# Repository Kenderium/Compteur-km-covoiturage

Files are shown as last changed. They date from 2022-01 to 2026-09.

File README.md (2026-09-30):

# The Carpool Project (CarpoX)

Covoiturez-vous souvent ? CarpoX est un boîtier à mettre dans la voiture qui
mesure au GPS les km de chaque trajet et note qui était à bord grâce à des
badges RFID. Une app calcule ensuite qui doit combien à qui, en tenant compte
de qui a payé chaque plein.

## Comment ça marche

```
 Boîtier (Pico W)                     Serveur Linux                App web (téléphone / PC)
 GPS + badges RFID  ── WiFi connu ──▶  API + base SQLite  ◀── HTTPS ──  comptes, pleins, soldes
        ▲                                                                    │
        └──────────────────────── Bluetooth (BLE) ───────────────────────────┘
               synchro via le téléphone, association des badges
```

1. **Dans la voiture** : on badge le conducteur puis les passagers, et le
   boîtier compte les km au GPS jusqu'à l'arrivée.
2. **Synchronisation** : dès que le boîtier voit un WiFi connu (maison, partage
   de connexion), il envoie ses trajets au serveur. On peut aussi le faire via
   le téléphone en Bluetooth, depuis l'app.
3. **Au plein** : celui qui paie saisit le prix (et, idéalement, les litres)
   dans l'app. Le plein est réparti sur les trajets faits depuis le plein
   précédent. L'app estime aussi le carburant restant.
4. **Soldes** : l'app affiche qui doit combien à qui, avec le minimum de
   virements. On y note aussi les remboursements, péages et parkings.
5. **Historique** : chaque trajet garde son parcours GPS, visible sur une carte.
6. **Home Assistant** (facultatif) : chacun peut afficher ses soldes, les km et
   le carburant estimé dans Home Assistant. Voir
   [`home-assistant/README.md`](home-assistant/README.md).

### Règle de partage

Chaque trajet coûte `km du trajet × prix au km du plein`, partagé à parts
égales entre les personnes à bord, conducteur compris. Un trajet fait seul est
payé par le conducteur ; un trajet à quatre coûte un quart à chacun. Les km
roulés sans que personne n'ait badgé (le boîtier les compte quand même), ou
indiqués en plus par le compteur journalier, restent à la charge de celui qui
a payé le plein. Les calculs se font
au centime près, sans jamais perdre ni créer de centime.

## Organisation du dépôt

| Dossier | Contenu |
|---|---|
| [`core/`](core/) | Logique partagée en Python pur : distances GPS, répartition des frais, soldes, import de l'ancien historique. Tourne sur le serveur et sur le Pico. |
| [`firmware/`](firmware/) | MicroPython pour le Raspberry Pi Pico W : écrans, GPS, badges, WiFi, Bluetooth. |
| [`server/`](server/) | Serveur FastAPI + SQLite : comptes, synchro, calcul des soldes. Sert aussi l'app. |
| [`app/`](app/) | App web installable (HTML/JS sans dépendance) : comptes, pleins, soldes, Bluetooth. |
| [`custom_components/carpox/`](custom_components/carpox/) | Intégration Home Assistant (installable avec HACS), documentée dans [`home-assistant/`](home-assistant/). |
| [`hardware/`](hardware/) | Brochage, schémas Fritzing, boîtier 3D, liste du matériel. |

## Démarrer

- Serveur et app : voir [`server/README.md`](server/README.md).
- Boîtier : voir [`firmware/README.md`](firmware/README.md) et
  [`hardware/README.md`](hardware/README.md).

L'app fonctionne dans tout navigateur. Le Bluetooth depuis l'app demande
Chrome ou Edge (Android, Windows, macOS, Linux) ; il n'est pas disponible sur
iPhone, où la synchro passe alors uniquement par le WiFi du boîtier.

## Tests

```bash
pip install -r server/requirements-dev.txt
pytest
```

Les tests de l'intégration Home Assistant se lancent à part (voir
[`home-assistant/README.md`](home-assistant/README.md)).

Les tests couvrent la logique de partage, le firmware (avec une simulation du
matériel qui envoie de vraies trames GPS) et l'API du serveur.

## Crédits

@LaTeam — Julien Dagnelie & Loïc Tumelaire (UCLouvain).

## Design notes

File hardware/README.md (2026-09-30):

# Matériel

| Élément | Rôle | Branchement sur le Pico W |
|---|---|---|
| Raspberry Pi **Pico W** | cerveau, WiFi et Bluetooth intégrés | |
| GPS NEO-6M | mesure des km | UART1 : TX du GPS → GP9, RX du GPS → GP8, 3V3, GND |
| Lecteur RFID RC522 | badges conducteur / passagers | SPI0 : SCK GP2, MOSI GP3, MISO GP4, CS GP6, RST GP5, 3V3, GND |
| Écran OLED SSD1306 128×64 (I2C) | affichage | I2C1 : SDA GP26, SCL GP27, 3V3, GND |
| Bouton « suivant » | menu suivant / annuler | GP14 ↔ 3V3 (pull-down interne) |
| Bouton « OK » | valider | GP15 ↔ 3V3 (pull-down interne) |
| LED verte / rouge | retours visuels | GP17 / GP16 via résistance ~220 Ω |

Les broches se changent dans `firmware/config.py`.

## Passage du Pico au Pico W

Le Pico W a le même brochage que le Pico : tout se rebranche à l'identique.

- **Le module Bluetooth HC-05/HC-06 n'est plus nécessaire** : le Pico W a le
  Bluetooth (BLE) intégré, utilisé directement par l'app. Les broches GP0/GP1 et
  GP13 (état du HC-05) sont libérées.
- Le module WiFi ESP8266 prévu en bonus n'est plus nécessaire non plus.
- Installer MicroPython **pour Pico W** (fichier `RPI_PICO_W-*.uf2` sur
  micropython.org), pas celui du Pico simple.

## Conseil pour le GPS

Le NEO-6M a besoin de voir le ciel : sans antenne près du pare-brise il peut
mettre plusieurs minutes à trouver sa position (l'écran « Etat » affiche le
nombre de satellites). Sa LED clignote une fois par seconde quand il a un fix.

## Fichiers

- `fritzing/` : schémas de câblage V1 et V2 (V2 = avec HC-06, à mettre à jour
  pour le Pico W)
- `boitier-3d/` : boîtier FreeCAD
- `materiel.md` : liens d'achat d'origine

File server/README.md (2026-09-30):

# Serveur CarpoX

API + base de données pour les boîtiers et l'app. Python 3.10+, FastAPI,
SQLite (un seul fichier, rien d'autre à installer).

## Ce qu'il fait

- **Comptes** : mots de passe hachés avec scrypt, sessions par jeton aléatoire
  (seule l'empreinte est stockée), blocage 15 min après 5 échecs, code
  d'invitation optionnel pour empêcher les inscriptions inconnues.
- **Voitures** : chaque boîtier est une voiture partagée par des membres. Le
  propriétaire reçoit un jeton de boîtier (affiché une seule fois) et un code
  Bluetooth à 6 chiffres.
- **Synchro** : `POST /api/device/sync` reçoit les trajets du boîtier en WiFi,
  `POST /api/devices/{id}/relay` les reçoit via l'app (Bluetooth). Les deux sont
  idempotents : un trajet renvoyé n'est jamais compté deux fois.
- **Comptes entre personnes** : pleins, frais partagés (péage, parking) et
  remboursements saisis dans l'app ; `GET /api/devices/{id}/summary` renvoie les
  soldes et les virements proposés, calculés par `core/carpox_core`.
- **Voitures** : le propriétaire règle le nom, la capacité du réservoir, la
  consommation moyenne et, s'il veut, le compteur à l'installation du boîtier
  (`PATCH /api/devices/{id}`). Le serveur en déduit le carburant restant, la
  consommation mesurée (grâce aux litres des pleins) et le compteur estimé.
- **Trajets et parcours** : `GET /api/devices/{id}/trips` liste les trajets
  badgés et les km roulés sans badge ; `GET /api/devices/{id}/trips/{n}` donne
  le parcours GPS, que l'app dessine sur une carte. Un parcours n'est montré
  qu'au propriétaire de la voiture et aux personnes à bord (les km sans badge :
  au propriétaire seul).
- **Jetons personnels** (`/api/me/tokens`) : pour Home Assistant ou un autre
  outil. Lecture seule, sans expiration, révocables, stockés sous forme
  d'empreinte. `GET /api/me/overview` regroupe en un appel tout ce qui concerne
  le compte. Voir [`home-assistant/README.md`](../home-assistant/README.md).
- Sert aussi l'app web (`app/`) à la racine du site.

La base existante est mise à jour toute seule au démarrage (nouvelles colonnes
et tables).

### Fond de carte

L'app dessine les parcours sur les tuiles d'OpenStreetMap, chargées par le
navigateur de chaque personne. Pour changer de fournisseur, définissez
`CARPOX_MAP_TILES` (modèle d'URL `https://.../{z}/{x}/{y}.png`) ; pour ne rien
charger de l'extérieur, laissez-la vide (`CARPOX_MAP_TILES=`) : l'app dessine
alors le tracé seul.

Documentation interactive de l'API : `/api/docs`.

## Lancer en local

```bash
python3 -m venv .venv && . .venv/bin/activate
pip install -r server/requirements-dev.txt
PYTHONPATH=core:server uvicorn carpox_server.main:app --reload
# puis http://localhost:8000
```

Tests : `pytest` à la racine du dépôt.

## Installer sur un serveur Linux (Debian/Ubuntu)

```bash
sudo useradd --system --home /opt/carpox carpox
sudo git clone https://github.com/Kenderium/Compteur-km-covoiturage /opt/carpox
sudo python3 -m venv /opt/carpox/.venv
sudo /opt/carpox/.venv/bin/pip install -r /opt/carpox/server/requirements.txt
sudo mkdir -p /var/lib/carpox && sudo chown carpox /var/lib/carpox
sudo cp /opt/carpox/server/deploy/carpox.service /etc/systemd/system/
sudo systemctl enable --now carpox
```

Puis un reverse proxy HTTPS devant (exemple Caddy dans `deploy/Caddyfile`,
à adapter avec votre nom de domaine). Le HTTPS est indispensable : il protège
les mots de passe et le jeton du boîtier, et le Bluetooth web ne fonctionne que
sur une page HTTPS.

Sauvegarde : copier `/var/lib/carpox/carpox.sqlite3` (par exemple avec
`sqlite3 carpox.sqlite3 ".backup sauvegarde.sqlite3"`).

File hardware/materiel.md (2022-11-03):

### <u>Box 3D (imprimé)</u>

### <u>Puce GPS</u>:
https://www.amazon.fr/ICQUANZX-GY-NEO6MV2-contr%C3%B4leur-antenne-c%C3%A9ramique/dp/B088LR3488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

### <u>Lecteur RFID (NFC $\to$ téléphone ?)</u>:
https://www.amazon.fr/ICQUANZX-lecteur-blanche-porte-cl%C3%A9s-Raspberry/dp/B088QZL3B6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

### <u> Module Bluethoot</u>:
https://www.amazon.fr/azdelivery-Bluetooth-Transceiver-RS232-TTL-Communication/dp/B0722MD4FY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

### <u>Ecran (affichage conducteur, kilomètres,...)</u>:
https://www.amazon.fr/AZDelivery-pouces-Arduino-Raspberry-microcontr%C3%B4leur/dp/B01L9GC470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

- Boutons 2x (start/stop + réinistialiser)
Led rouge + verte (bonne lecture des cartes)

## <u>Bonus:

### <u>Module Wifi pour stats;...</u>:
https://www.amazon.fr/AZDelivery-ESP8266-Arduino-Raspberry-microcontr%C3%B4leur/dp/B01LK83TX0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

#### <u>Haut parleur (annoncer le pilote ;) )</u>:
https://www.amazon.fr/Isd1820-son-lecture-denregistrement-parleur-Haut-parleur/dp/B06XD96N4J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

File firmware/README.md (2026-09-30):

# Firmware du boîtier (Raspberry Pi Pico W, MicroPython)

## Installation

1. Installer MicroPython pour **Pico W** : maintenir BOOTSEL en branchant le
   Pico W, puis copier le fichier `RPI_PICO_W-*.uf2` de micropython.org.
2. Dans l'app, onglet **Voitures > Ajouter** : l'app affiche l'identifiant, le
   jeton et le code Bluetooth du boîtier.
3. `cp firmware/config_example.py firmware/config.py`, puis y coller ces valeurs,
   l'adresse du serveur et vos réseaux WiFi.
4. `pip install mpremote` puis `firmware/tools/deploy.sh` (boîtier branché en USB).

Mettre à jour le firmware plus tard : relancer `deploy.sh`. Les trajets déjà
enregistrés (`journal.jsonl`) restent sur le boîtier.

## Utilisation

Deux boutons : **SUIVANT** (menu suivant / annuler) et **OK** (valider).

- **Nouveau trajet** : badge du conducteur, puis badges des passagers, OK pour
  partir. L'écran affiche les km en direct. OK à l'arrivée, puis OK pour
  confirmer. Si le courant est coupé en route, le boîtier propose de reprendre
  le trajet au redémarrage.
- **Historique** : derniers trajets (SUIVANT pour défiler).
- **Synchro WiFi** : envoie les trajets tout de suite. Sinon le boîtier le fait
  seul toutes les 5 minutes quand il voit un WiFi connu et n'est pas en trajet.
- **Scanner badge** : affiche le numéro d'un badge, pour l'associer à une
  personne depuis l'app (onglet Boîtier).
- **Etat** : trajets en attente, km roulés sans badge, satellites GPS, Bluetooth.

### Km comptés sans badge

Le boîtier est alimenté par la voiture : dès qu'elle roule, il compte les km,
même si personne n'a badgé. Hors trajet, ces km sont regroupés par segment :
un segment se termine après `DRIVE_IDLE_S` secondes à l'arrêt (3 minutes par
défaut, dans `config.py`) ou à la coupure du contact, puis il est envoyé au
serveur comme les trajets. Ils servent à estimer le carburant restant, et
sont à la charge de celui qui paie le plein suivant. Quand un trajet badgé
démarre, c'est lui qui compte les km.

Les trajets et ces segments gardent leur **parcours** (un point tous les
200 m environ, 250 points au plus), visible dans l'app, onglet Trajets.

Les frais ne se calculent plus sur le boîtier : les pleins se saisissent dans
l'app et les soldes sont calculés par le serveur.

## Organisation

```
main.py              démarrage
config_example.py    modèle de configuration (config.py n'est pas versionné)
carpox/app.py        écrans et boucle principale (non bloquante)
carpox/gps.py        lecture du GPS sur l'UART
carpox/trip.py       trajet en cours, km via carpox_core.geo
carpox/drive.py      km roulés sans badge
carpox/track.py      parcours simplifié (points GPS)
carpox/journal.py    trajets numérotés, stockés en JSON lines
carpox/wifi.py       synchro WiFi
carpox/ble.py        Bluetooth BLE (service Nordic UART)
carpox/protocol.py   commandes Bluetooth (AUTH, STATUS, EVENTS, APPLY, BADGE, LASTSCAN)
carpox/sync.py       protocole de synchro commun au WiFi et au Bluetooth
lib/                 pilotes GPS (micropyGPS), RFID (mfrc522), écran (ssd1306)
tests/               tests sous CPython, avec une simulation du matériel
```

`deploy.sh` copie aussi `core/carpox_core/geo.py` (calcul des distances).

## Sécurité

- Le jeton du boîtier ne sert qu'à envoyer ses trajets. S'il est perdu,
  régénérez-le dans l'app (onglet Membres) et mettez à jour `config.py`.
- Le Bluetooth demande le code à 6 chiffres de la voiture ; après 5 codes faux
  il faut se reconnecter. La liaison BLE n'est pas chiffrée : elle ne transporte
  que des trajets et des noms de badges, jamais de mot de passe.
- Utilisez une adresse `https://` pour le serveur.

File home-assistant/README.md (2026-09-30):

# CarpoX dans Home Assistant

L'intégration `carpox` affiche dans Home Assistant les km, le carburant estimé
et les soldes de vos voitures CarpoX. Elle lit le serveur CarpoX avec un
**jeton personnel en lecture seule** : elle ne peut rien modifier.

Chaque personne lie **son propre compte** CarpoX. Dans un Home Assistant
partagé, on peut ajouter plusieurs comptes (une entrée par compte). Attention :
dans Home Assistant, tous les utilisateurs d'une même instance voient les
mêmes capteurs. La séparation se fait par compte CarpoX, pas par utilisateur HA.

## Installation

### Avec HACS (conseillé)

1. HACS > menu ⋮ > **Dépôts personnalisés** : ajoutez
   `https://github.com/Kenderium/Compteur-km-covoiturage`, catégorie
   **Intégration**.
2. Installez **CarpoX**, puis redémarrez Home Assistant.

### À la main

Copiez le dossier `custom_components/carpox` de ce dépôt dans le dossier
`custom_components/` de votre configuration Home Assistant, puis redémarrez.

## Lier son compte

1. Dans l'app CarpoX, onglet **Compte** > **Home Assistant et autres
   applications** : donnez un nom au jeton (« Home Assistant maison ») et
   cliquez **Créer un jeton**. Copiez-le : il n'est affiché qu'une fois.
2. Dans Home Assistant : **Paramètres > Appareils et services > Ajouter une
   intégration > CarpoX**. Entrez l'adresse du serveur (celle de l'app, par
   exemple `https://carpox.mondomaine.be`) et le jeton.

Le jeton n'expire pas. Révoquez-le dans l'app quand il ne sert plus :
Home Assistant vous demandera alors un nouveau jeton. Changer de mot de passe
ne révoque pas les jetons.

La fréquence de mise à jour (10 minutes par défaut, de 5 à 60) se règle dans
les options de l'intégration.

## Ce que vous obtenez

Un appareil par voiture, avec :

| Capteur | Contenu |
|---|---|
| Km depuis le plein | km roulés depuis le dernier plein, avec ou sans badge |
| Carburant estimé | litres restants (attributs : réservoir, date et litres du dernier plein) |
| Niveau du réservoir estimé | en % |
| Autonomie estimée | km possibles avec le carburant restant |
| Consommation | L/100 km, mesurée grâce aux litres des pleins, sinon celle réglée par le propriétaire |
| Km totaux | tous les km comptés par le boîtier (attributs : avec et sans badge) |
| Km sans badge | km roulés sans que personne n'ait badgé |
| Compteur estimé | compteur de la voiture, si le propriétaire a donné le compteur à l'installation |
| Mes km | vos km dans cette voiture |
| Mon solde | ce que vous avez avancé (+) ou devez (−) ; attributs `je_dois` et `on_me_doit` |
| Remboursements à faire | nombre de virements proposés ; attributs `virements` (« Julien → Loïc : 12.50 € ») et `soldes` de tout le monde |
| Dernière synchro | quand le boîtier a envoyé ses trajets pour la dernière fois |
| Dernier trajet | km du dernier trajet (attributs : départ, arrivée, à bord) |
| Trajets | nombre de trajets |
| Dernière position | `device_tracker` : fin du dernier parcours GPS reçu que vous pouvez voir (le propriétaire voit tout, les autres membres seulement les trajets où ils étaient à bord) |

Et un appareil « CarpoX *votre nom* » avec votre solde total, ce que vous
devez, ce qu'on vous doit et vos km sur toutes les voitures.

### Estimation du carburant

Elle suppose que chaque plein remplit le réservoir. Le propriétaire indique
la capacité du réservoir et la consommation moyenne dans l'app (onglet
**Voiture**). Si on note les litres à chaque plein, la consommation réelle
est calculée sur les derniers pleins et remplace celle réglée. Le boîtier
compte les km dès qu'il est allumé, même si personne n'a badgé.

### Limites

- **Pas de position en direct** : le boîtier n'envoie ses trajets que
  lorsqu'il capte un WiFi connu (en général à la maison). La position et les
  km sont donc ceux de la dernière synchro.
- « Dernière synchro » récente veut souvent dire « voiture à la maison » :
  pratique pour les automatisations.

## Exemples

Carte de tableau de bord :

```yaml
type: entities
title: Golf
entities:
  - sensor.golf_carburant_estime
  - sensor.golf_autonomie_estimee
  - sensor.golf_km_depuis_le_plein
  - sensor.golf_mon_solde
  - sensor.golf_derniere_synchro
```

Rappel quand le réservoir est presque vide :

```yaml
automation:
  - alias: "Golf : faire le plein"
    triggers:
      - trigger: numeric_state
        entity_id: sensor.golf_niveau_du_reservoir_estime
        below: 15
    actions:
      - action: notify.notify
        data:
          message: "Plus que {{ states('sensor.golf_autonomie_estimee') }} km d'autonomie dans la Golf."
```

Les noms exacts des entités dépendent du nom de la voiture et de la langue de
Home Assistant : vérifiez-les dans **Paramètres > Appareils et services >
CarpoX**.

## Sans l'intégration (capteur REST)

L'API est lisible directement : `GET /api/me/overview` avec l'en-tête
`Authorization: Bearer <jeton>`. Par exemple :

```yaml
rest:
  - resource: https://carpox.mondomaine.be/api/me/overview
    headers:
      Authorization: !secret carpox_token
    scan_interval: 600
    sensor:
      - name: "CarpoX solde"
        unit_of_measurement: "EUR"
        value_template: "{{ value_json.totals.balance_cents / 100 }}"
```

avec `carpox_token: "Bearer cpx_..."` dans `secrets.yaml`.

## Développement

Tests (Python 3.13) :

```bash
pip install -r home-assistant/requirements-test.txt
cd home-assistant && pytest
```

`tests/overview.json` est la réponse type du serveur. Les tests du serveur
vérifient qu'il renvoie bien ces clés, ce qui garde l'intégration et le
serveur d'accord.

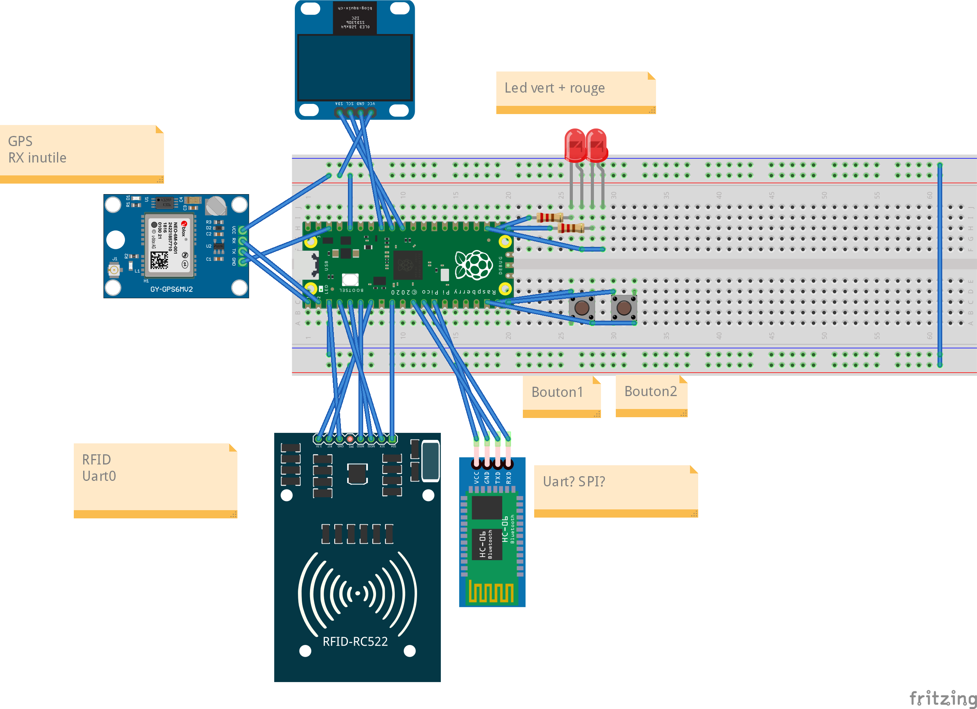
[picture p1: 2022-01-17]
hardware/fritzing/Covoiturage-V2_bb.png

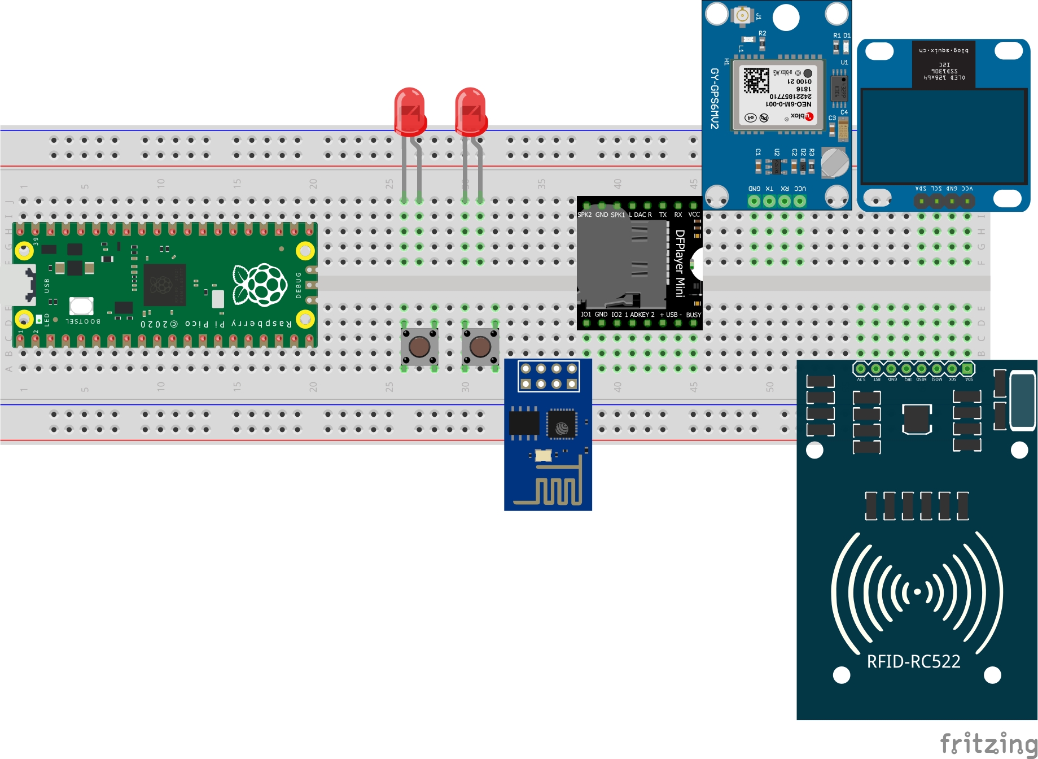
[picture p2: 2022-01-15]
hardware/fritzing/Covoiturage-V1_bb.jpg

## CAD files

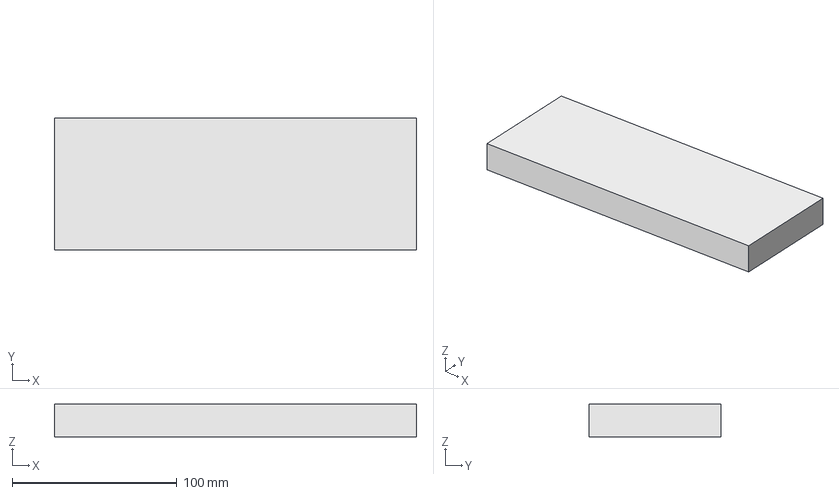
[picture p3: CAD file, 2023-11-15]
hardware/boitier-3d/Box.FCStd
220.0 x 80.0 x 20.0 mm

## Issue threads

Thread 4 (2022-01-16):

Problème affichage ligne et rectangle sur l'écran

Kenderium, 2022-01-16:
**Describe the bug**
Bug code "inconnu" ?

**To Reproduce**
oled.line
oled.rect
oled.fill_rect

**Expected behavior**
Puisse run le code

**Screenshots**
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

@JulienDagnelie

Kenderium, 2022-01-16:
https://www.tomshardware.com/how-to/oled-display-raspberry-pi-pico

Closed 2022-11-03.

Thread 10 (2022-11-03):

Centraliser infos sur un serveur

Kenderium, 2022-11-03:
**Is your feature request related to a problem? Please describe.**
Centraliser informations (historiques) de tous les appareils sur un serveur, pour centraliser et comparer les infos.
+ Lien avec l'application?

**Describe the solution you'd like**
Envois des informations de manières sécurisées de la box au serveur.

**Describe alternatives you've considered**
Ou bien de l'app vers le serveur

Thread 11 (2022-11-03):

Faire le wiki "HowToUse"

Kenderium, 2022-11-03:
**Is your feature request related to a problem? Please describe.**
Compléter le wiki du github

**Describe the solution you'd like**
Un beau wiki en couleur avec des photos !!

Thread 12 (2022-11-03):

Bug dans la lecture de l'historique

Kenderium, 2022-11-03:
**Describe the bug**
Problème dans la lecture de l'historique, tous les passagers ne sont pas lus correctement lors du calcul du prix.

**To Reproduce**
Steps to reproduce the behavior:
1. Juste démarre le calcul d'un plein
2. Tous les passagers ne sont pas pris en compte

**Expected behavior**
Avoir tous les passagers dans le calcul ;-)

**Additional context**
Aller check le .split() ......

Closed 2022-11-11.

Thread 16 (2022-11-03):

Utiliser téléphone pour encodage passager/conducteur

Kenderium, 2022-11-03:
**Is your feature request related to a problem? Please describe.**
Utiliser le NFC pour s'encoder, comme les cartes/tags

**Describe the solution you'd like**
Scanner le téléphone en nfc à la place des tags/cartes.

**Describe alternatives you've considered**
Ou via bluethoot, mais moins rapide.

**Additional context**
Apparemment le numéro renvoyé du nfc des smartphones change... A test

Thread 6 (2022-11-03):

Bug même conducteur quand on redémarre un trajet

Kenderium, 2022-11-03:
**To Reproduce**
Steps to reproduce the behavior:
1. Encoder un chauffeur
2. Exit
3. Run et démarrer directement le voyage

**Expected behavior**
Reprendre le chauffeur

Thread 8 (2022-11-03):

Usure

JulienDagnelie, 2022-11-03:
**Prise en compte de l'usure**
Pour le moment, le programme ne prends pas en compte l'usure de la voiture, assurance etc pour le pilote. Peut-etre faudrait-il?

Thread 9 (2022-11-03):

Application pour le plein et récupérer stats

Kenderium, 2022-11-03:
**Is your feature request related to a problem? Please describe.**
Une application pour encoder le prix du plein et les km pour recevoir qui doit combien à celui qui a payé le plein + afficher les stats (en graphs?)

**Describe the solution you'd like**
Une belle app.

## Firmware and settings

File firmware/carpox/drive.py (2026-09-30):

"""Km roulés sans trajet badgé.

Le boîtier est alimenté par la voiture : il compte les km dès que la voiture
roule, même si personne n'a badgé. Ces km servent à estimer le carburant
restant, et sont à la charge de celui qui paie le plein suivant.

Un « segment » commence au premier déplacement et se termine quand la voiture
reste immobile `idle_s` secondes (ou au démarrage suivant, si le courant a
été coupé). Il est alors écrit au journal comme un événement "drive".
"""

from carpox_core.geo import DistanceAccumulator
from carpox.track import Track


class DriveRecorder:
    def __init__(self, min_step_m=25.0):
        self.min_step_m = min_step_m
        self.acc = DistanceAccumulator(min_step_m=min_step_m)
        self._clear()

    def _clear(self):
        self.track = Track()
        self.started_at = None
        self.ended_at = None
        self.last_move_s = None

    @property
    def active(self):
        """Vrai dès que la voiture a vraiment bougé (pas un GPS qui tremble)."""
        return self.acc.total_m > 0

    @property
    def km(self):
        return self.acc.total_km

    def add_fix(self, lat, lon, t_s=None, hdop=None, now_s=None, unix_ts=None):
        """Ajoute une position. `now_s` : horloge monotone du boîtier, en secondes."""
        before_m = self.acc.total_m
        origin = self.acc.position
        if not self.acc.add(lat, lon, t_s, hdop):
            return False
        if self.acc.total_m > before_m:
            if self.started_at is None:
                self.started_at = unix_ts
                if origin is not None:
                    self.track.add(origin[0], origin[1])
            self.track.add(lat, lon)
            self.ended_at = unix_ts
            self.last_move_s = now_s
        return True

    def idle_for(self, now_s):
        if not self.active or self.last_move_s is None or now_s is None:
            return 0
        return now_s - self.last_move_s

    def close(self, keep_position=True):
        """Termine le segment. Retourne l'événement à écrire au journal, ou None.

        `keep_position` : le prochain segment repart de la dernière position,
        pour ne perdre aucun mètre. À désactiver quand un trajet badgé
        commence, car c'est alors lui qui compte les km.
        """
        event = None
        if self.active:
            event = {
                "type": "drive",
                "km": round(self.acc.total_km, 3),
                "start": self.started_at,
                "end": self.ended_at,
                "gps_points": self.acc.points,
                "track": self.track.finish(),
            }
        self.acc.restart(keep_position)
        self._clear()
        return event

    def snapshot(self):
        """État à sauvegarder : la coupure du contact coupe aussi le boîtier."""
        return {
            "total_m": self.acc.total_m,
            "points": self.acc.points,
            "started_at": self.started_at,
            "ended_at": self.ended_at,
            "track": self.track.copy() if self.active else [],
        }

    def restore(self, state):
        self.acc.total_m = state.get("total_m", 0.0)
        self.acc.points = state.get("points", 0)
        self.started_at = state.get("started_at")
        self.ended_at = state.get("ended_at")
        self.track = Track(points=state.get("track"))

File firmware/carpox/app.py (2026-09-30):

"""Boucle principale du boîtier.

La boucle ne bloque jamais longtemps : à chaque tour elle lit les boutons,
le GPS, le lecteur RFID et les commandes Bluetooth. Chaque écran est un état.

Boutons : SUIVANT (menu suivant / annuler) et OK (valider).

Le boîtier compte les km dès qu'il est allumé (donc dès que la voiture
roule) : hors trajet badgé, ils vont dans des segments "drive" (carpox.drive).
"""

import json
import time

import config
from carpox import clock, wifi
from carpox.badges import Badges
from carpox.ble import BleUart
from carpox.drive import DriveRecorder
from carpox.gps import Gps
from carpox.hw import Hardware
from carpox.journal import Journal
from carpox.protocol import CommandHandler
from carpox.rfid import RfidReader
from carpox.trip import TripRecorder

MENU = ["Nouveau trajet", "Historique", "Synchro WiFi", "Scanner badge", "Etat"]
TRIP_STATE_FILE = "trip_state.json"
DRIVE_STATE_FILE = "drive_state.json"
SAVE_EVERY_MS = 30000
RFID_EVERY_MS = 250
# Segment hors trajet terminé après N secondes à l'arrêt (config.DRIVE_IDLE_S).
DRIVE_IDLE_S = getattr(config, "DRIVE_IDLE_S", 180)


def _save_state(path, recorder):
    with open(path, "w") as f:
        f.write(json.dumps(recorder.snapshot()))


def _clear_state(path):
    try:
        import os
        os.remove(path)
    except OSError:
        pass


def _load_state(path):
    try:
        with open(path) as f:
            return json.loads(f.read())
    except (OSError, ValueError):
        return None


def _save_trip(recorder):
    _save_state(TRIP_STATE_FILE, recorder)


def _clear_trip():
    _clear_state(TRIP_STATE_FILE)


class App:
    def __init__(self):
        self.hw = Hardware()
        self.hw.show("CarpoX", "Demarrage...")
        self.journal = Journal()
        self.badges = Badges()
        self.recorder = TripRecorder()
        self.drive = DriveRecorder()
        self.gps = Gps()
        self.rfid = RfidReader()
        self.handler = CommandHandler(config.DEVICE_ID, config.BLE_PIN, self.journal,
                                      self.badges, self.recorder, clock, self.drive)
        self.ble = BleUart(config.BLE_NAME, self.handler)
        self.state = "menu"
        self.menu_index = 0
        self.history = []
        self.history_index = 0
        self.message_until = 0
        self.last_rfid_ms = 0
        self.last_save_ms = 0
        self.last_drive_save_ms = 0
        self.last_sync_s = time.time() - config.SYNC_INTERVAL_S + 20  # 1re synchro ~20 s après démarrage
        self.dirty = True

        # Km roulés hors trajet avant la dernière coupure du contact.
        saved = _load_state(DRIVE_STATE_FILE)
        if saved:
            self.drive.restore(saved)
            self.close_drive(keep_position=False)

        saved = _load_state(TRIP_STATE_FILE)
        if saved and saved.get("driver"):
            self.recorder.restore(saved)
            self.state = "resume"

    # --- utilitaires -------------------------------------------------------

    def goto(self, state):
        self.state = state
        self.dirty = True

    def message(self, *lines, ms=1500, then="menu"):
        self.hw.show(*lines)
        self.message_until = time.ticks_add(time.ticks_ms(), ms)
        self.after_message = then
        self.state = "message"

    def scan_badge(self):
        now = time.ticks_ms()
        if time.ticks_diff(now, self.last_rfid_ms) < RFID_EVERY_MS:
            return None
        self.last_rfid_ms = now
        uid = self.rfid.read()
        if uid:
            self.handler.last_scan = uid
        return uid

    # --- boucle ------------------------------------------------------------

    def run(self):
        while True:
            self.poll_inputs()
            self.step()
            time.sleep_ms(20)

    def poll_inputs(self):
        """Bluetooth et GPS. Les km comptent toujours : dans le trajet s'il y en
        a un, sinon dans le segment hors trajet."""
        self.ble.poll()
        fix = self.gps.poll()
        if fix:
            if self.recorder.active:
                if self.recorder.add_fix(*fix):
                    self.dirty = True
            else:
                self.drive.add_fix(fix[0], fix[1], fix[2], fix[3], time.time(), clock.now())
        if self.drive.active:
            if self.drive.idle_for(time.time()) >= DRIVE_IDLE_S:
                self.close_drive()
            elif time.ticks_diff(time.ticks_ms(), self.last_drive_save_ms) > SAVE_EVERY_MS:
                _save_state(DRIVE_STATE_FILE, self.drive)
                self.last_drive_save_ms = time.ticks_ms()

    def close_drive(self, keep_position=True):
        """Écrit au journal les km roulés hors trajet depuis le dernier arrêt."""
        event = self.drive.close(keep_position)
        if event is not None and event["km"] > 0:
            self.journal.append(event)
        _clear_state(DRIVE_STATE_FILE)

    def step(self):
        nxt = self.hw.next.pressed()
        ok = self.hw.ok.pressed()
        getattr(self, "state_" + self.state)(nxt, ok)

    # --- écrans ------------------------------------------------------------

    def state_message(self, nxt, ok):
        if nxt or ok or time.ticks_diff(time.ticks_ms(), self.message_until) >= 0:
            self.goto(self.after_message)

    def state_menu(self, nxt, ok):
        if nxt:
            self.menu_index = (self.menu_index + 1) % len(MENU)
            self.dirty = True
        if ok:
            self.hw.blink(self.hw.led_green, 150)
            choice = MENU[self.menu_index]
            if choice == "Nouveau trajet":
                self.recorder.reset()
                self.goto("driver")
            elif choice == "Historique":
                self.history = self.journal.recent(20, "trip")
                self.history.reverse()
                self.history_index = 0
                self.goto("history")
            elif choice == "Synchro WiFi":
                self.sync_now()
            elif choice == "Scanner badge":
                self.goto("scan")
            elif choice == "Etat":
                self.goto("status")
            return
        if time.time() - self.last_sync_s >= config.SYNC_INTERVAL_S and self.journal.pending_count():
            self.sync_now(quiet=True)
            return
        if self.dirty:
            item = MENU[self.menu_index]
            pending = self.journal.pending_count()
            self.hw.show("CarpoX", "", "> " + item, "", "",
                         ("%d a envoyer" % pending) if pending else ("BT connecte" if self.ble.connected() else ""))
            self.dirty = False

    def sync_now(self, quiet=False):
        self.last_sync_s = time.time()
        self.hw.show("Synchro WiFi...")
        ok, msg = wifi.try_sync(self.journal, self.badges)
        if quiet and not ok:
            self.goto("menu")
        else:
            self.message("Synchro WiFi", "OK" if ok else "Echec", msg, ms=2000)
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

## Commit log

2021-10-24 test led1
2022-01-16 init du programme de covoiturage
2022-01-16 init des fichiers de code
2022-01-17 Add files via upload
    bug....oups
    [Covoiturage-V2.fzz]
2022-01-19 bug uart?
2022-02-01 corrections leds
2022-02-26 to de covoit
2023-11-15 3D box is starting
    [Box.FCStd]
2026-09-30 Réorganise le dépôt et isole la logique de répartition des frais
    - core/carpox_core : distances GPS (haversine corrigée), répartition des
    pleins par trajet, soldes et remboursements, import de l'ancien historique
    - firmware/lib : bibliothèques MicroPython conservées (GPS, RFID, écran)
    - hardware/ : schémas Fritzing, boîtier 3D, liste du matériel
    - Supprime l'ancien code du boîtier (réécrit dans les commits suivants)
    Claude-Session: https://claude.ai/code/session_01ARJGR77XBAb8tDX3KCp71i
    [Box.FCStd, Covoiturage-V1.fzz, Covoiturage-V2.fzz]
2026-09-30 Réécrit le firmware pour le Pico W avec le GPS branché
    - Le GPS lit enfin l'UART (l'ancien code n'alimentait jamais le parseur)
    et additionne les km avec un filtre anti-tremblement
    - Boucle non bloquante : boutons, GPS, RFID et Bluetooth en parallèle
    - Bluetooth BLE intégré au Pico W (plus de HC-05), protégé par un code
    - Journal des trajets numérotés, synchro WiFi vers le serveur
    - Trajet sauvegardé en cours de route (coupure de courant)
    - Noms des badges reçus du serveur au lieu d'être codés en dur
    - Tests CPython, dont une simulation complète avec de vraies trames NMEA
    Claude-Session: https://claude.ai/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
    [app.py, badges.py, ble.py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]
2026-09-30 Ajoute le serveur : comptes sécurisés, synchro des boîtiers, soldes
    - FastAPI + SQLite, mots de passe scrypt, jetons stockés hachés,
    blocage après 5 échecs, code d'invitation optionnel
    - Synchro idempotente depuis le boîtier (WiFi) ou relayée par l'app (BLE)
    - Pleins, frais partagés et remboursements ; soldes et virements proposés
    - Badges liés aux comptes ou aux invités
    - Fichiers de déploiement systemd + Caddy (HTTPS)
    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
2026-09-30 Ajoute l'app web (comptes, pleins, soldes, Bluetooth) et la documentation
    - App HTML/JS sans dépendance servie par le serveur : connexion,
    voitures, soldes et virements, saisie des pleins/frais/remboursements,
    journal, membres et badges
    - Liaison Bluetooth (Web Bluetooth) : synchro des trajets via le
    téléphone et association des badges
    - README réécrits (projet, serveur, firmware, matériel Pico W)
    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
2026-09-30 Ajoute l'intégration Home Assistant, les km sans badge et les parcours
    - Firmware : le boîtier compte les km dès qu'il est allumé, même sans badge
    (segments "drive"), et garde le parcours GPS des trajets. Le journal est lu
    ligne par ligne et les envois sont limités en taille pour la mémoire du Pico.
    - Serveur : jetons personnels en lecture seule et révocables, réglages de la
    voiture par le propriétaire (nom, réservoir, consommation, compteur), litres
    au plein, estimation du carburant, /api/me/overview, historique des trajets
    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
